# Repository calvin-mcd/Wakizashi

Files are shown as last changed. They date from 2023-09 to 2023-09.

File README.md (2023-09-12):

# Wakizashi
 
Another collaboration with Falconloft4615. The wakizashi is a simple controller drop in PCB, with the aim to support BLE controller. This is a katana staggered layout with an adundance of options for the alpha cluster as well as the bottomrow.

## Layout

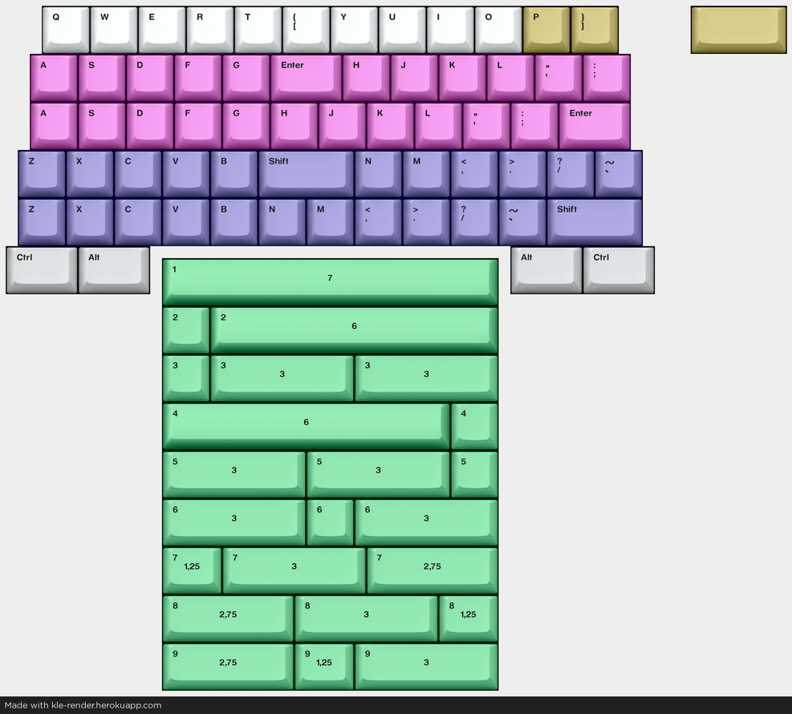
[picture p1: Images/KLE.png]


[Link](http://www.keyboard-layout-editor.com/#/gists/63cf34c3830b2de49229a321a906cf57)

## Pictures

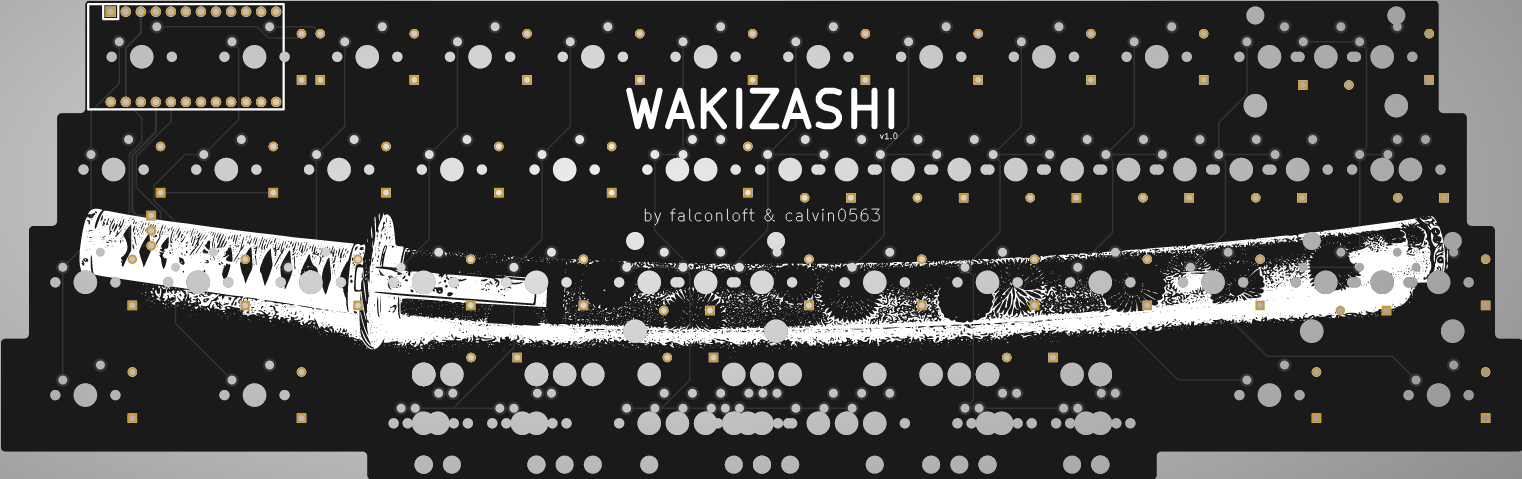
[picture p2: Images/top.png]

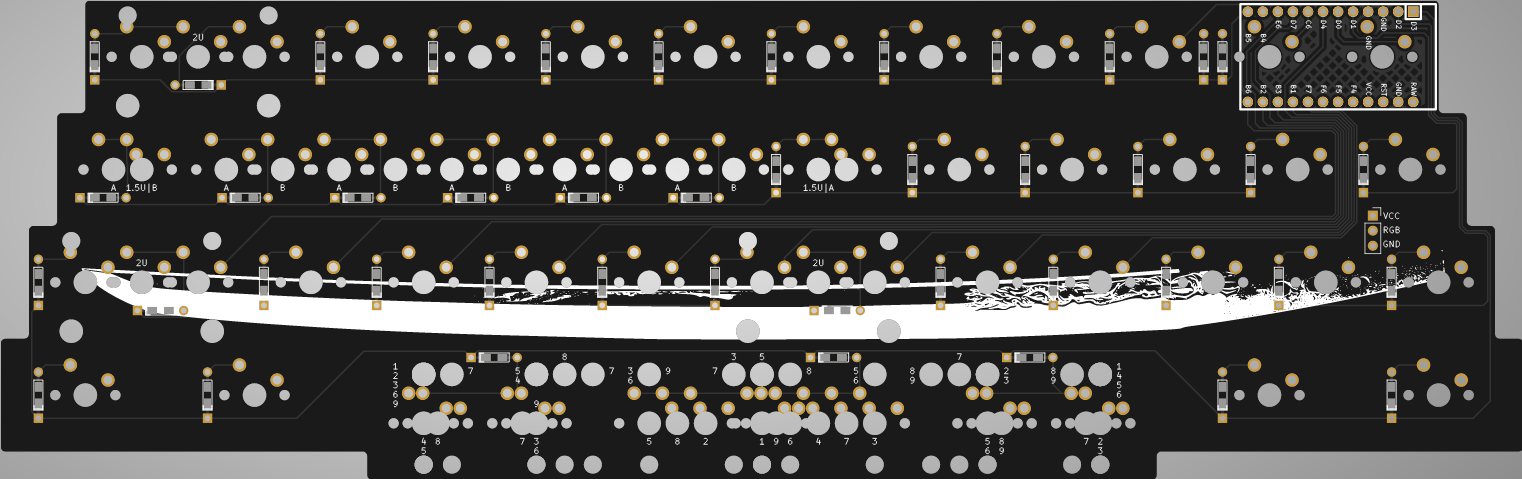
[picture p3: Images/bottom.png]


## Todo

- [ ] order & test pcb
- [ ] create firmware
- [ ] create simple sandwhich case 

## Disclaimer

Please note that this project is a work in progress with no guarantees of a working outcome. No-one involved in this project is responsible for any usage issues that may arise. Order at your own risk. Support will not be provided but pull requests will be reviewed and possibly accepted.

## License

Shield: 

This work is licensed under a  
[Creative Commons Attribution-NonCommercial-ShareAlike 4.0 International License](http://creativecommons.org/licenses/by-nc-sa/4.0/).



## Credits

Any questions, contact Falconloft4615 & Calvin0563 on Discord.

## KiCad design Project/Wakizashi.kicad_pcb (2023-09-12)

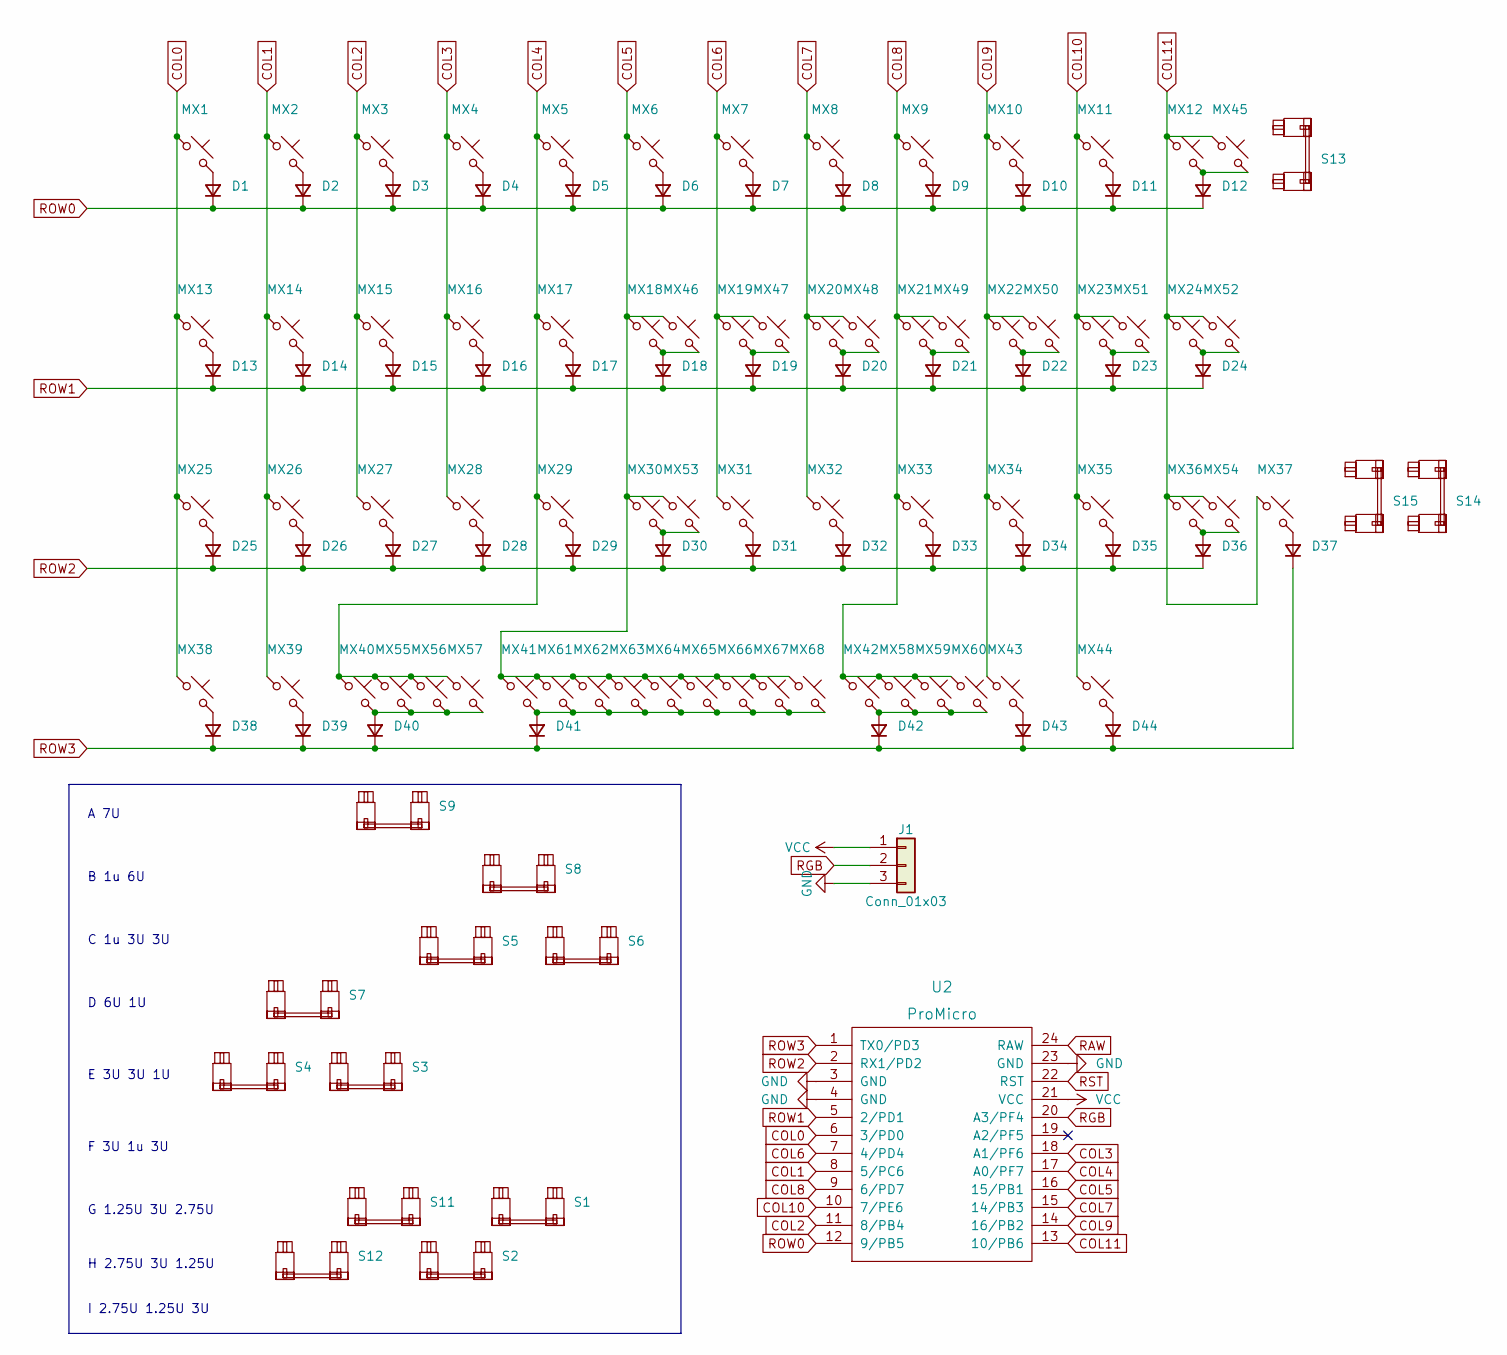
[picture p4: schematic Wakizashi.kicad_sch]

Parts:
D1, D2, D3, D4, D5, D6, D7, D8, D9, D10, D11, D12, D13, D14, D15, D16, D17, D18, D19, D20, D21, D22, D23, D24, D25, D26, D27, D28, D29, D30, D31, D32, D33, D34, D35, D36, D37, D38, D39, D40, D41, D42, D43, D44: D_Small; Diode-Hybrid-Back
J1: Conn_01x03; PinSocket_1x03_P2.54mm_Vertical
MX1, MX2, MX3, MX4, MX5, MX6, MX7, MX8, MX9, MX10, MX11, MX12, MX13, MX14, MX15, MX16, MX17, MX18, MX19, MX20, MX21, MX22, MX23, MX24, MX25, MX26, MX27, MX28, MX29, MX30, MX31, MX32, MX33, MX34, MX35, MX36, MX37, MX40, MX41, MX42, MX45, MX47, MX48, MX49, MX50, MX51, MX53, MX54, MX55, MX56, MX58, MX59, MX61, MX62, MX63, MX64, MX65, MX66, MX67: MX_SW_solder; SW_MX_1u
MX38, MX39, MX43, MX44, MX46, MX52: MX_SW_solder; SW_MX_1.5u
MX57, MX60, MX68: MX_SW_solder; SW_MX_1.25u
S1, S12: MX_stab; STAB_MX_2.75u
S2, S3, S4, S5, S6, S11: MX_stab; STAB_MX_3u
S7, S8: MX_stab; STAB_MX_6u
S9: MX_stab; STAB_MX_7u
S13, S14, S15: MX_stab; STAB_MX_2u
U2: ProMicro; ArduinoProMicro

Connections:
COL0: MX1.1, MX13.1, MX25.1, MX38.1, U2.6 (3/PD0)
COL1: MX2.1, MX14.1, MX26.1, MX39.1, U2.8 (5/PC6)
COL2: MX3.1, MX15.1, MX27.1, U2.11 (8/PB4)
COL3: MX4.1, MX16.1, MX28.1, U2.18 (A1/PF6)
COL4: MX5.1, MX17.1, MX29.1, MX40.1, MX55.1, MX56.1, MX57.1, U2.17 (A0/PF7)
COL5: MX6.1, MX18.1, MX30.1, MX41.1, MX46.1, MX53.1, MX61.1, MX62.1, MX63.1, MX64.1, MX65.1, MX66.1, MX67.1, MX68.1, U2.16 (15/PB1)
COL6: MX7.1, MX19.1, MX31.1, MX47.1, U2.7 (4/PD4)
COL7: MX8.1, MX20.1, MX32.1, MX48.1, U2.15 (14/PB3)
COL8: MX9.1, MX21.1, MX33.1, MX42.1, MX49.1, MX58.1, MX59.1, MX60.1, U2.9 (6/PD7)
COL9: MX10.1, MX22.1, MX34.1, MX43.1, MX50.1, U2.14 (16/PB2)
COL10: MX11.1, MX23.1, MX35.1, MX44.1, MX51.1, U2.10 (7/PE6)
COL11: MX12.1, MX24.1, MX36.1, MX37.1, MX45.1, MX52.1, MX54.1, U2.13 (10/PB6)
GND: J1.3, U2.3 (GND), U2.4 (GND), U2.23 (GND)
unnamed: D1.2 (A), MX1.2
unnamed: D2.2 (A), MX2.2
unnamed: D3.2 (A), MX3.2
unnamed: D4.2 (A), MX4.2
unnamed: D5.2 (A), MX5.2
unnamed: D6.2 (A), MX6.2
unnamed: D7.2 (A), MX7.2
unnamed: D8.2 (A), MX8.2
unnamed: D9.2 (A), MX9.2
unnamed: D10.2 (A), MX10.2
unnamed: D11.2 (A), MX11.2
unnamed: D12.2 (A), MX12.2, MX45.2
unnamed: D13.2 (A), MX13.2
unnamed: D14.2 (A), MX14.2
unnamed: D15.2 (A), MX15.2
unnamed: D16.2 (A), MX16.2
unnamed: D17.2 (A), MX17.2
unnamed: D18.2 (A), MX18.2, MX46.2
unnamed: D19.2 (A), MX19.2, MX47.2
unnamed: D20.2 (A), MX20.2, MX48.2
unnamed: D21.2 (A), MX21.2, MX49.2
unnamed: D22.2 (A), MX22.2, MX50.2
unnamed: D23.2 (A), MX23.2, MX51.2
unnamed: D24.2 (A), MX24.2, MX52.2
unnamed: D25.2 (A), MX25.2
unnamed: D26.2 (A), MX26.2
unnamed: D27.2 (A), MX27.2
unnamed: D28.2 (A), MX28.2
unnamed: D29.2 (A), MX29.2
unnamed: D30.2 (A), MX30.2, MX53.2
unnamed: D31.2 (A), MX31.2
unnamed: D32.2 (A), MX32.2
unnamed: D33.2 (A), MX33.2
unnamed: D34.2 (A), MX34.2
unnamed: D35.2 (A), MX35.2
unnamed: D36.2 (A), MX36.2, MX54.2
unnamed: D37.2 (A), MX37.2
unnamed: D38.2 (A), MX38.2
unnamed: D39.2 (A), MX39.2
unnamed: D40.2 (A), MX40.2, MX55.2, MX56.2, MX57.2
unnamed: D41.2 (A), MX41.2, MX61.2, MX62.2, MX63.2, MX64.2, MX65.2, MX66.2, MX67.2, MX68.2
unnamed: D42.2 (A), MX42.2, MX58.2, MX59.2, MX60.2
unnamed: D43.2 (A), MX43.2
unnamed: D44.2 (A), MX44.2
RAW: U2.24 (RAW)
RGB: J1.2, U2.20 (A3/PF4)
ROW0: D1.1 (K), D2.1 (K), D3.1 (K), D4.1 (K), D5.1 (K), D6.1 (K), D7.1 (K), D8.1 (K), D9.1 (K), D10.1 (K), D11.1 (K), D12.1 (K), U2.12 (9/PB5)
ROW1: D13.1 (K), D14.1 (K), D15.1 (K), D16.1 (K), D17.1 (K), D18.1 (K), D19.1 (K), D20.1 (K), D21.1 (K), D22.1 (K), D23.1 (K), D24.1 (K), U2.5 (2/PD1)
ROW2: D25.1 (K), D26.1 (K), D27.1 (K), D28.1 (K), D29.1 (K), D30.1 (K), D31.1 (K), D32.1 (K), D33.1 (K), D34.1 (K), D35.1 (K), D36.1 (K), U2.2 (RX1/PD2)
ROW3: D37.1 (K), D38.1 (K), D39.1 (K), D40.1 (K), D41.1 (K), D42.1 (K), D43.1 (K), D44.1 (K), U2.1 (TX0/PD3)
RST: U2.22 (RST)
VCC: J1.1, U2.21 (VCC)

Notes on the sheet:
G 1.25U 3U 2.75U
D 6U 1U
H 2.75U 3U 1.25U
C 1u 3U 3U
A 7U
B 1u 6U
E 3U 3U 1U
F 3U 1u 3U
I 2.75U 1.25U 3U

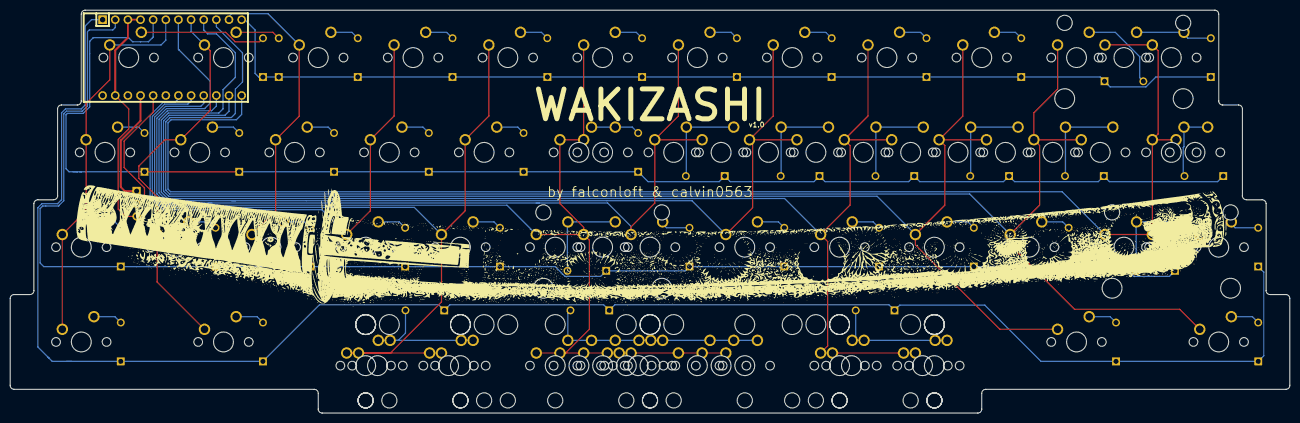
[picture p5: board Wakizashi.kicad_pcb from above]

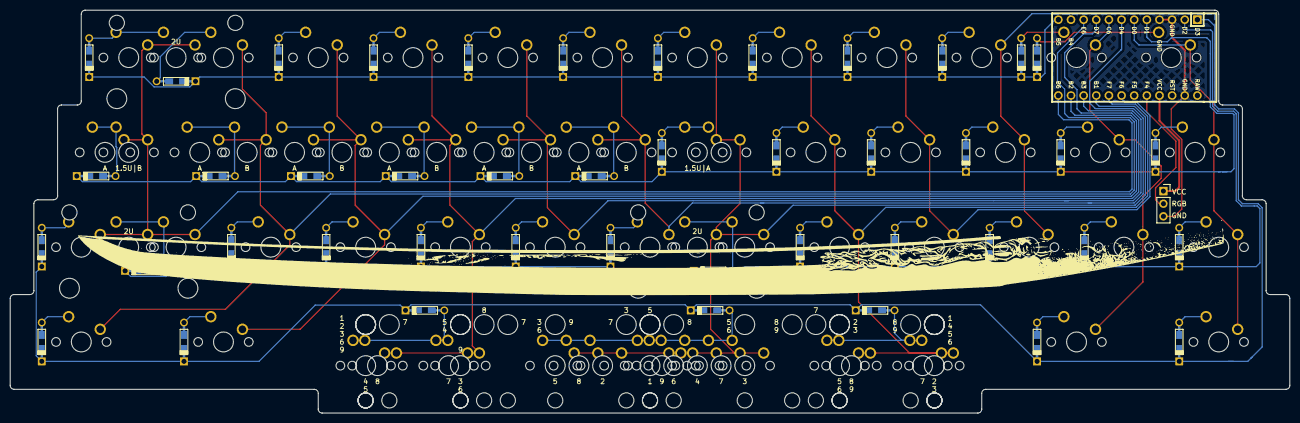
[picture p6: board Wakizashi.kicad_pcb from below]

Board: 2 copper layers, 257.2 x 81.0 mm, 128 parts (2 on the bottom side), 63 nets.

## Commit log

2023-09-11 cleaning up project
    [Wakizashi.kicad_pcb, Wakizashi.kicad_sch]
2023-09-12 update project
    [Wakizashi-B_Cu.gbr, Wakizashi-B_Mask.gbr, Wakizashi-B_Paste.gbr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]
